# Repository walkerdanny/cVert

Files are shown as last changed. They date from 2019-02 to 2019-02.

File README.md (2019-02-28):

#☢🎹 cVert 🎛☢

### A truly random MIDI controller

YouTube video:

<a href="http://www.youtube.com/watch?feature=player_embedded&v=vMFJ8gjN8Ac
" target="_blank">Video Emo</a>

cVert is a MIDI controller which plays completely random notes based on the radioactive decay of radioisotopes.

Find out more about cVert [on my website](http://danny.makesthings.work/cVert) or [in this zine](https://github.com/walkerdanny/cVert/blob/master/documentation/zine.pdf).

All documentation, code, mechanical files, gerbers etc. are included in this repository. A list of libraries required to compile the software is included in the "electrical" directory.

### Disclaimer: Don't play with radioisotopes unless you're completely sure what you're doing. I'm not responsible if you decide to mess with a dangerous material without taking the proper precautions. Background radiation in most areas will give you a sufficient amount of counts to make cVert a useful tool without introducing extra radioactive material.

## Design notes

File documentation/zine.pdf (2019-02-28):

# cVert

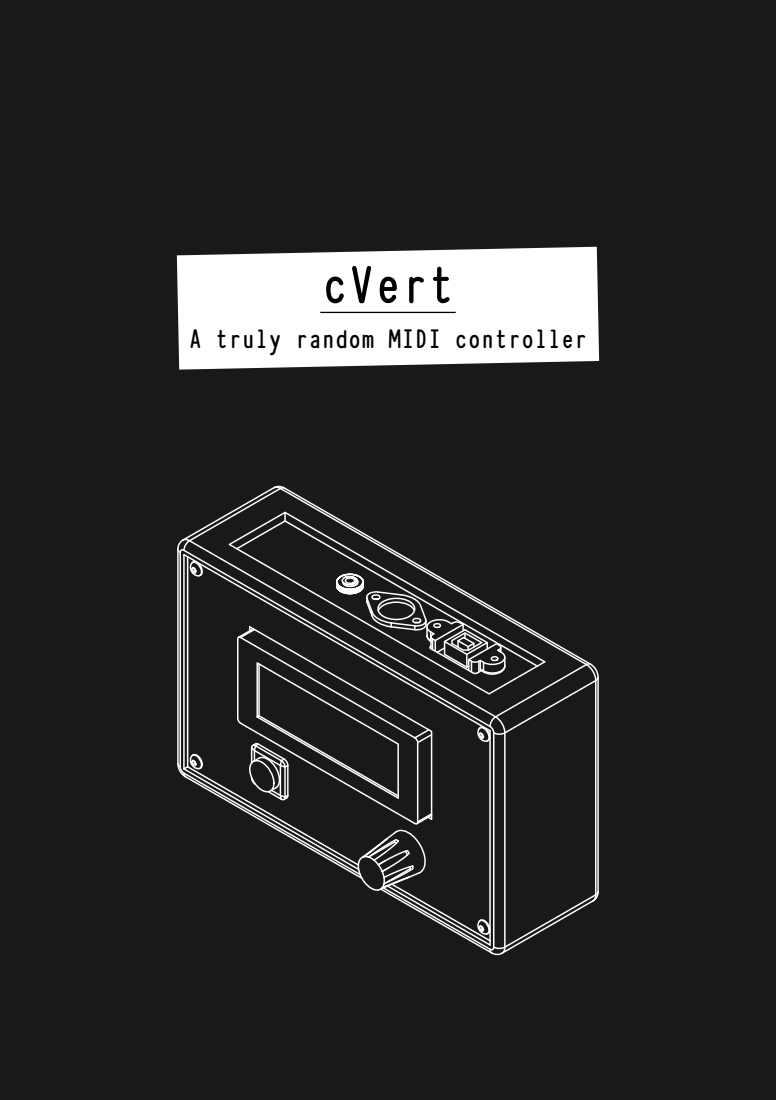
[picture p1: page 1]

A truly random MIDI controller

# What?

cVert qsee-vurtT is a different type of MIDI controller.

Rather than imitating a traditional instrument, cVert generates random notes at random times, based on the radioactive decay of unstable elements.

cVert contains a Geiger–Müller tube, which detects radioactivity. It uses this as an input to generate MIDI notes. Since the decay of unstable isotopes is inherently unpredictable, the notes which are generated are truly and completely random.

cVert can limit the notes it generates to suit a specifc scale or range, according to a series of user selected parameters.

cVert also features a 32 step sequencer. The steps of the sequencer are filled with randomly selected notes, one of which will change each time a
a radioactive decay is detected.

# What for?

cVert can be used for a huge range of weird thingsY Here are some examples for inspirationY

Music:

Interesting results can be produced by using cVert in sequencer mode to control a drum machineS or to play segments of a chopped up sampleS like an amen break or a vocal clipY

In single note modeS cVert can generate ambient soundsY Using it to play a reverbed piano provides relaxingS contemplative background musicY

cVert can also be used to add an unpredictable element to a live performanceY Utilising the MIDI out feature enables cVert to be easily integrated into an existing live setupY Please consider the experimental nature of cVert when doing thisS as the MIDI out is not isolated and may be unreliableY

WARNING: DO NOT MESS WITH RADIOISOTOPES UNLESS YOU KNOW WHAT YOUNRE DOINGY Stick to just background radiation if youNre not completely sureY

Generative art:

When combined with the right software0 cVert can be used to produce random visual art2

Using the IMidiBusI library and Processing0 cVert can provide a random input for a generative artwork2 In fact0 all of the background art in this zine was generated using this techniquek cVert can also be used with platforms such as openFrameworks or Cinder0 or to control web1based applications via the Web MIDI API2

If the range of possible pitches and note numbers -)1x27D is not big enough for your application0
a recommended technique is to use a counter which constantly increments up to your desired maximum value2 cVert can then be used to stop the counter when a note is played0 resulting in a random number in a useful range2

Weird stuff:

If you really want to dive into the nitty gritty of what cVert can be used for0 Pure Data is a graphical programming environment which lets you process MIDI data on the fly2 It can do lots of fun things0 including live audio and visuals2

# How is it made?

cVert is an open-source projectS so all of the design files are available free of charge so that you can make your own.

The functional part of cVert is an Arduino Pro MicroS a cheap Geiger counter module and a few external pars such as a 555 timer and some resistors. While the components are fairly simpleS having a basic knowledge of electronics Cor help from someone who doesB is recommended if you want to build your own.

A custom PCB is available for cVert to make assembly simpleS however it can also be built
on perf board. This way cVert can suit the needs of individuals who want to add features or change componentsS whilst being permanent enough for a regularly used device.

The case for cVert is designed to be 3D printed and laser cut. While these technologies are becoming more accessible via hackerspaces etcS they are not yet available to all. The internals of cVert can therefore be fitted into a standard ABS project boxS available from a range of online stores Caluminium not recommended as it may attenuate the radiationB.

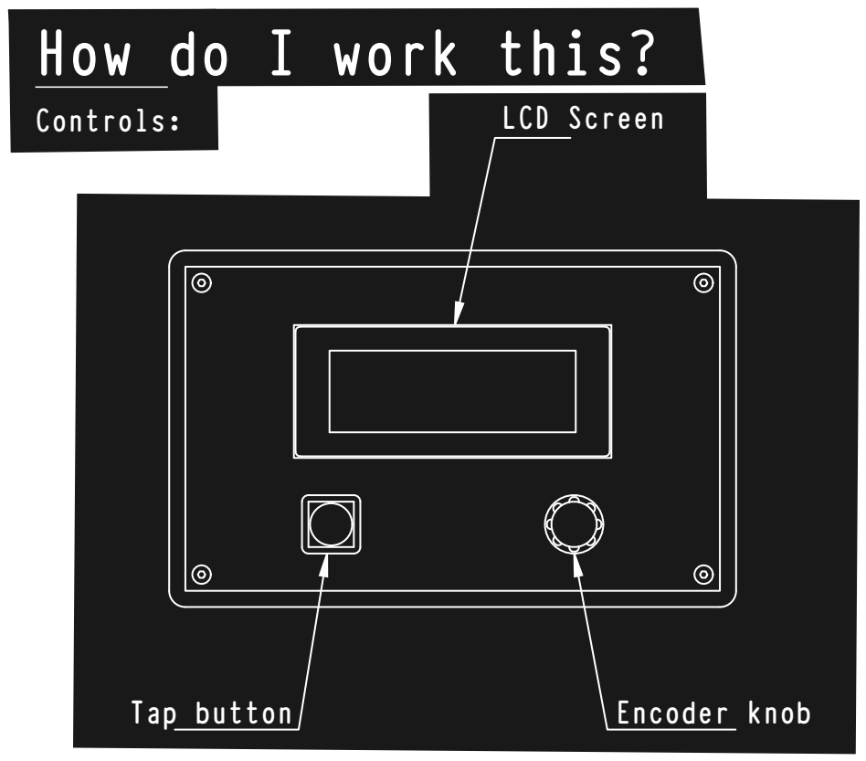
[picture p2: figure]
How do I work this?; LCD Screen; Tap button; Encoder knob; Controls:

The front panel features a 20 x 4 character LCD display, an encoder knob and a tap button.

Turn the encoder knob to navigate the menu or to change a parameter, and click it in to select. Clicking and holding the encoder knob will clear all steps from the step sequencer.

The tap button is used to simulate a decay event, i.e. to force cVert to generate a random note right now.

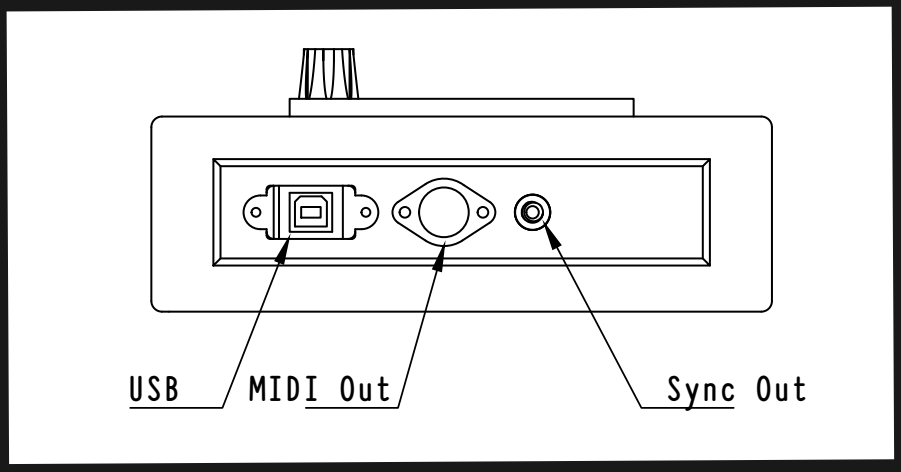
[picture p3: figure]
USB; MIDI Out; Sync Out

The rear panel features connections for USBO MIDI and for syncing external devices.

The USB plug is used to provide power to cVert and to communicate with a computer when used as a USB MIDI controller.

The 5 pin DIN socket is used to provide MIDI out to external hardware synthesisers etc. cVert still needs to be powered via USB 0e.g. a phone chargerR when using hardware synthesisers.

The 3.5mm jack provides a 5V clock signal 00.5ms high pulseO tip positiveR for syncing cVert with external hardware.

Rear Panel:

4 | 1 | 2 | 3

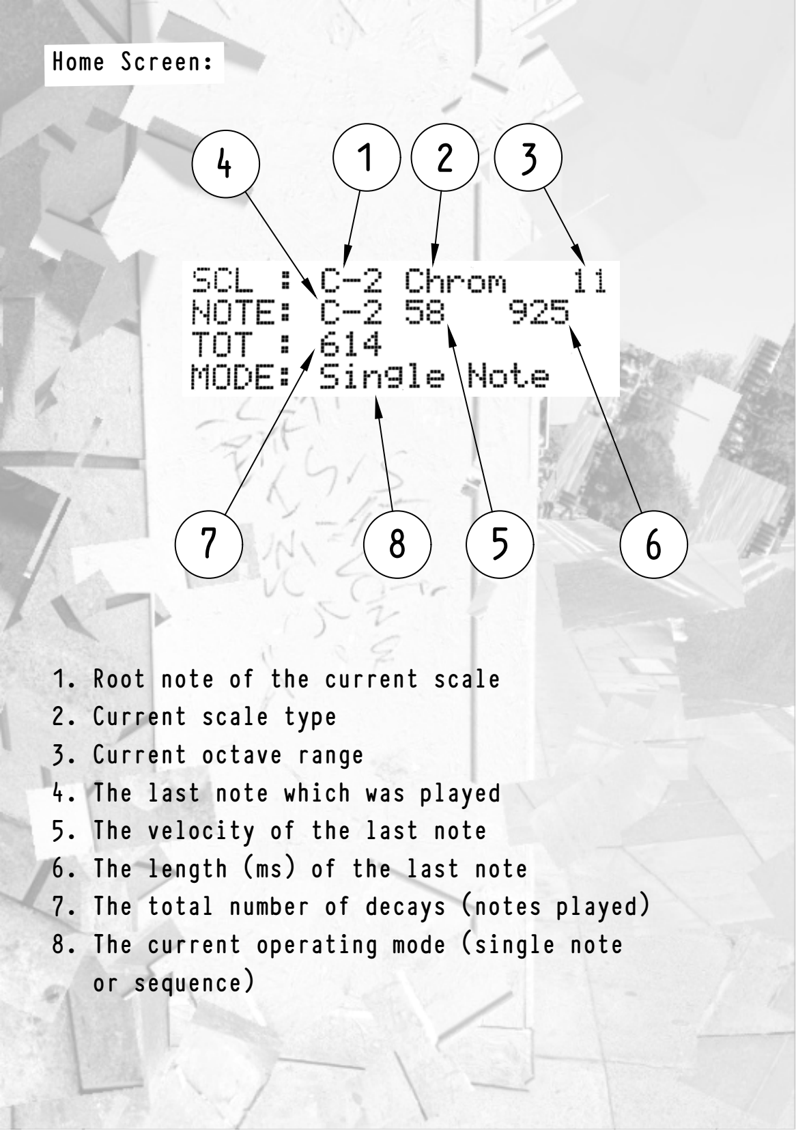
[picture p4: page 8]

### 1. Root note of the current scale 2. Current scale type 3. Current octave range 4. The last note which was played 5. The velocity of the last note 6. The length (ms) of the last note 7. The total number of decays (notes played) 8. The current operating mode (single note

or sequence)

7 | 8 | 5 | 6

Home Screen:

Menu Options:

Click the encoder knob in when at the home screen to enter the menuV

HOME x Returns to the home screenV

Mode x Switches between single note and sequencer modesV

Scale Type x Change the scale which notes are selected fromV "None" means the same note is always playedV Use "Chromatic" to play all notes within the selected rangeV

Root Note x Selects the root note of the scale/ from Cx2 to G8V

Range x The number of octaves of the selected scale to select notes fromV )x11V

Min(Max Velocity: Change the upper and lower limits of the range of velocities to play notes atV Set these to be equal for no velocity variationV

Note length: The length 8in msv to play each note for in single note modeV

Sequencer steps - The number of steps to use when in sequencer mode. 4E 8E 16 or 32.

Sequencer BPM - Sets the tempo in beats per minute of the sequencer. Only approximate due to microcontroller limitationsE use MIDI notes if true synchronisation is needed.

Sequencer divider - number of times per beat a note will be played.

Brightness - Adjusts the brightness of the case LEDsE if present.

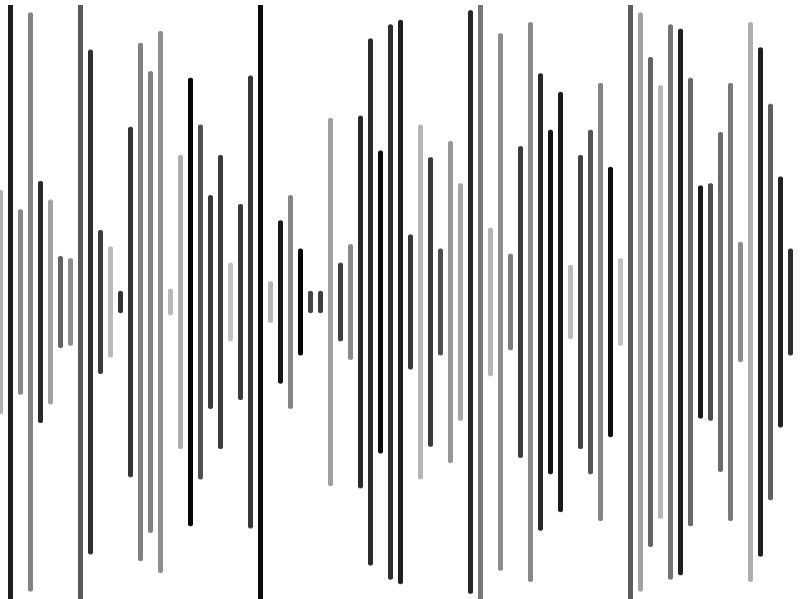
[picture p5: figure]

# More Info

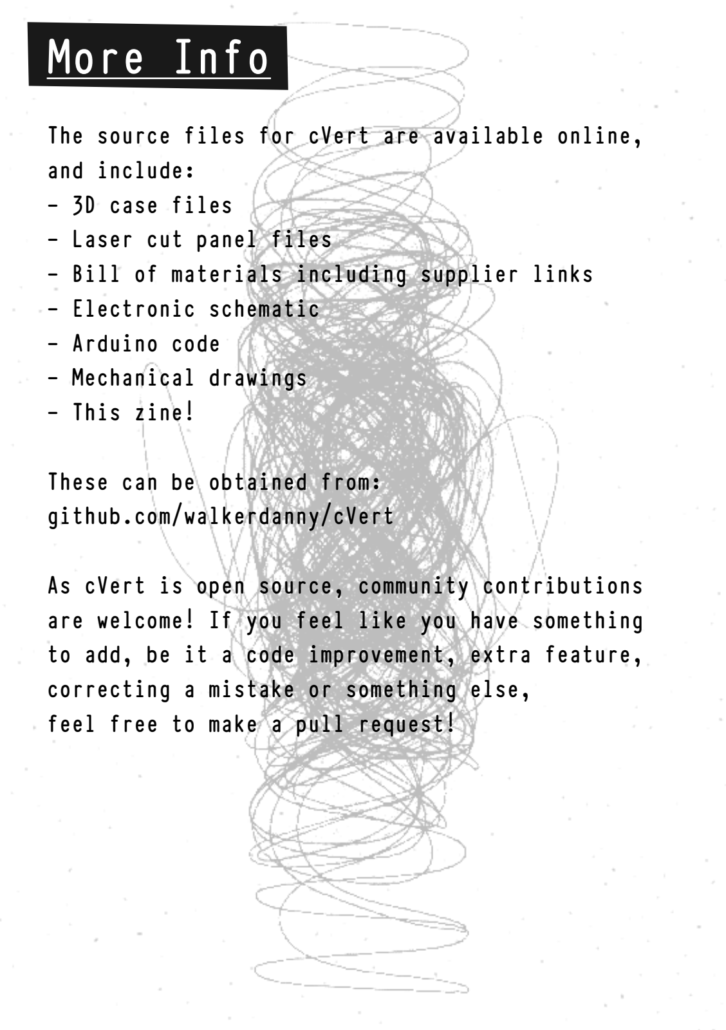
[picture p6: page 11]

The source files for cVert are available online, and include:
- 3D case files
- Laser cut panel files
- Bill of materials including supplier links
- Electronic schematic
- Arduino code
- Mechanical drawings
- This zineA

These can be obtained from: github.com/walkerdanny/cVert

As cVert is open source, community contributions are welcomeA If you feel like you have something to add, be it a code improvement, extra feature, correcting a mistake or something else,
feel free to make a pull requestA

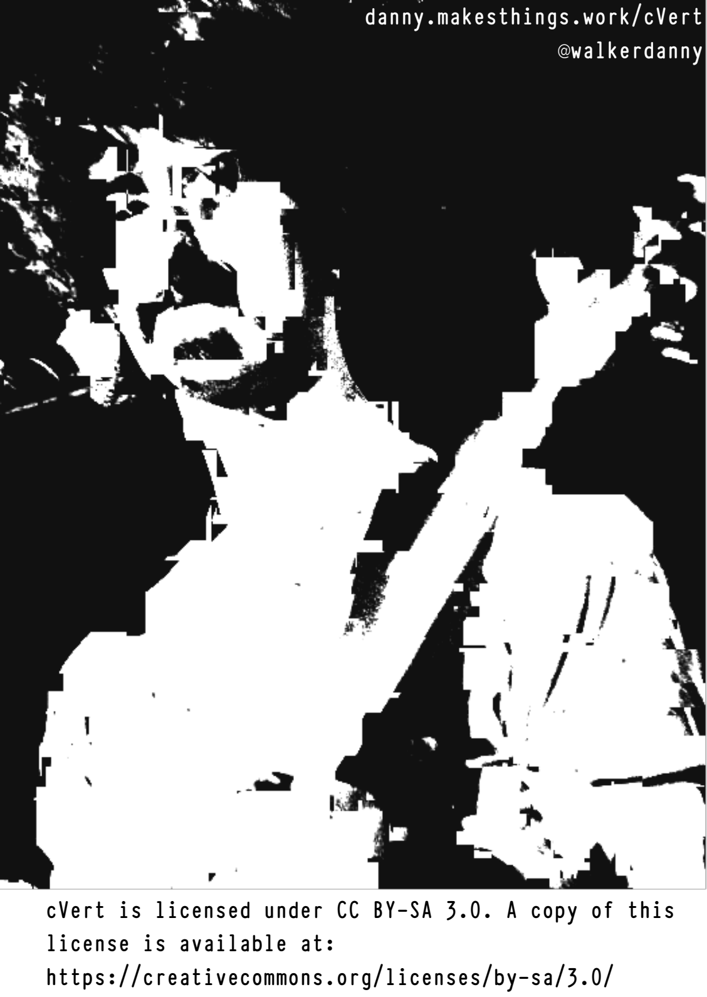
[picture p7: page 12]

cVert is licensed under CC BY-SA 3.0. A copy of this license is available at:
https://creativecommons.org/licenses/by-sa/3.0/danny.makesthings.work/cVert @walkerdanny

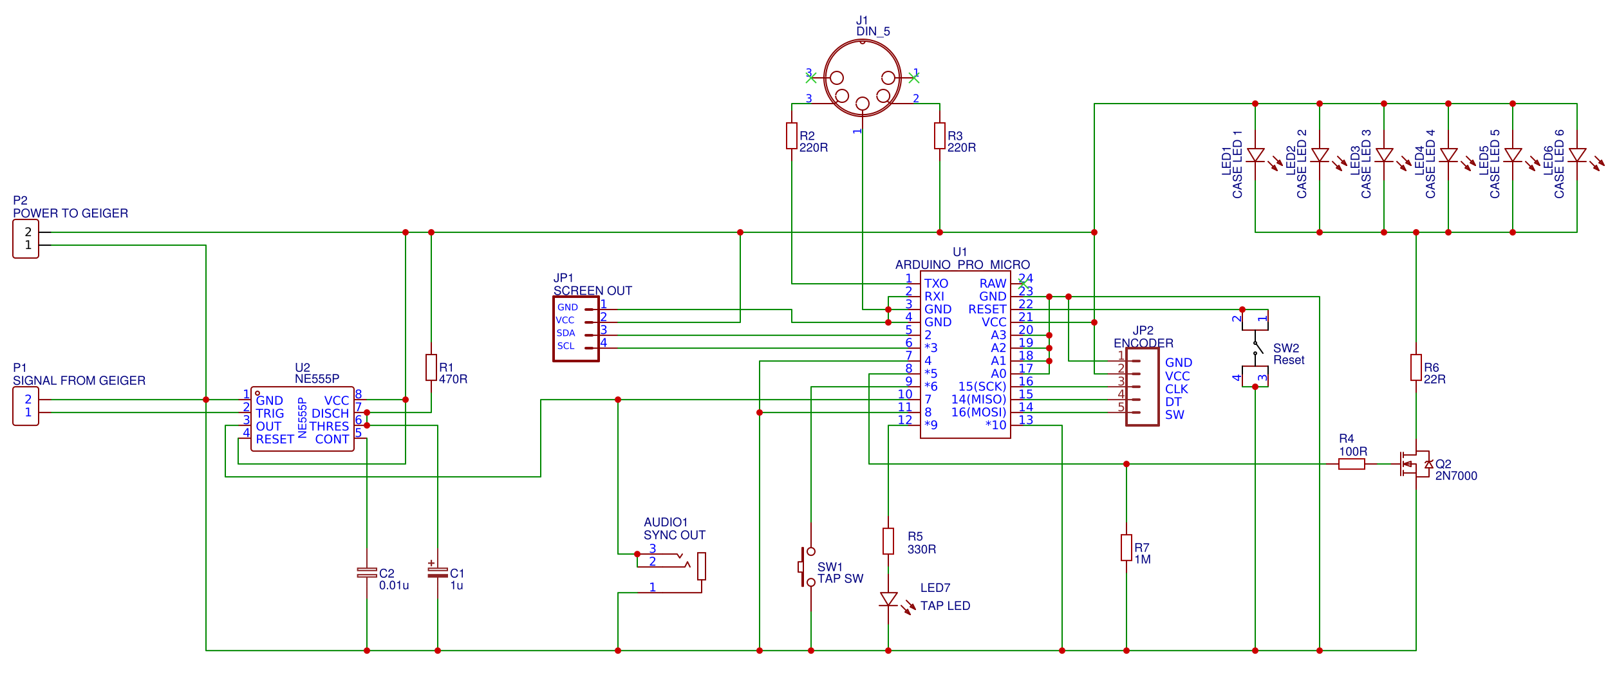
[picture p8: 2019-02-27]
electrical/schematic.png

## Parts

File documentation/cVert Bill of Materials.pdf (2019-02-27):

cVert Bill of Materials | Rev 0 - February 2019
Note: Required components are the absolute minimum to build a working cVert. To build one as featured in the documentation, all optional components should be included. Some consumables have been omitted (solder, superglue, hot glue etc.). Tools are also not listed.
Double check all components before ordering. If in doubt, email and ask.
Name | Required/Optional | Quantity | Source | Link | Notes
Arduino Pro Micro | R | 1 Online | https://www.sparkfun.com/products/12640 5V version needed. Clones available from Chinese drop shipping websites/eBay
Geiger Counter module | R | 1 Online | https://www.banggood.com/Assembled-DIY-Geiger-Counter-Kit-Module-Miller-Tube-GM-Tube-Nuclear-Radiation-Detector-p-1136883.html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 Also avaiable on AliExpress. Ensure it includes the tube before ordering.
20 x 4 LCD Module with I2C | R | 1 Online | https://www.banggood.com/IIC-I2C-2004-204-20-x-4-Character-LCD-Display-Module-Yellow-Green-p-908821.html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 Available elsewhere, ensure it includes I2C
Rotary Encoder module | R | 1 Online | https://www.banggood.com/KY-040-Rotary-Decoder-Encoder-Module-For-Arduino-AVR-PIC-p-914010.html?rmmds=search Available elsewhere, ensure it includes a switch and a D-Shaft for the knob to fit
Illuminated momentary push switch | R | 1 Maplin | https://uk.rs-online.com/web/p/push-button-switches/6911634/ Maplin is now defunct, linked button is similar but may require a different size hole in the panel
5 Pin, 180 Degree DIN Socket | R | 1 Maplin | https://www.ebay.co.uk/p/5-Pin-DIN-Chassis-Panel-Mount-Female-Socket-Connector-Solder-Midi-Cable-Adapter/1590247802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 Maplin is now defunct, linked socket is similar. Screws/nuts may need to be purchased separately.
3.5mm female socket, panel mount | R | 1 Maplin | https://www.ebay.co.uk/itm/3-5mm-Stereo-Jack-Socket-Chassis-Panel-Mount-Solder-Connector-Audio-Adapter/310760800278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 Maplin is now defunt, linked socket is similar.
NE555 Timer, 8 pin DIP | R | 1 Own stock https://www.ebay.co.uk/itm/NE555-NE555P-555-Timer-IC-8-pin-DIL-Pack-of-10/142389711946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 Common IC, available from any electronics store
Resistors (various) | R | | 4 Own stock | | 1/4 watt resistors of various values, see schematic. Can be ordered individually or in bulk. 2 additional if using case LEDs
Electrolytic capacitor, 1uF 16V | R | | 1 Own stock | | Available from lots of online retailers.
Ceramic capacitor, 10pF | R | | 1 Own stock | | Available from lots of online retailers.
2.54mm pitch female header | R | 47 Online | https://www.ebay.co.uk/itm/PCB-Header-Pins-Sockets-2-54mm-Pitch-Straight-Plugs-PIC-Arduino-Pi-Breadboard/131921173215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 Needed in smaller sections, quantity is the number of pins total.
Dupont male-female cables | R | 19 Online | https://www.ebay.co.uk/itm/40-pcs-Dupont-Cables-M-F-M-M-F-F-Jumper-Breadboard-Wire-GPIO-Ribbon-Pi-Arduino/263021195544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 Helps to order a selection of genders and colours. Some will be cut up and soldered onto things.
Perfboard (70x40mm) | R | 1 Online | https://www.banggood.com/40pcs-FR-4-Double-Side-Prototype-PCB-Printed-Circuit-Board-p-995732.html?rmmds=search Not required if using the custom PCB.
USB A to micro USB cable | R | | 1 Own stock | | For programming the Arduino. Can also be used as the main power/ data cable if desired.
P2N2222A Transistor | O | | 1 Own stock | | Available from lots of online retailers.
Custom cVert PCB | O | | 1 JLCPCB | See GitHub | Currently unavailable for purchase, but Gerbers are available for you to order your own. I may have some spares if you email me.
3D Printed Case (+ knob) | O | | 1 Self print | See GitHub | Can be printed via an online printing service, preferably black PLA
Laser cut acrylic panels (set) | O | 1 Self made See GitHub | Can be laser cut via onlie service if needed. Use 3mm translucent green acrylic. Possible to manufacture by hand.
M3 brass heat set inserts | O | 4 Online | https://www.ebay.co.uk/itm/M3-M4-M5-M6-Threaded-Solid-Brass-Press-in-Barbed-Inserts-for-plastic-press-fit/262993790868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
Black M3x12 dome head machine screw | O | 4 Online | https://www.ebay.co.uk/itm/M3-BLACK-HIGH-TENSILE-10-9-BUTTON-HEAD-ALLEN-BOLTS-SELF-COLOUR-DOME-SOCKET-SCREW/121829578789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
Black enamel spray paint | O | 1 Homebase https://www.homebase.co.uk/rust-oleum-painters-touch-craft-enamel-spray-paint-black-matt-150ml_p232471
Grey automotive spray primer | O | | 1 Own stock
1206 bright white LEDs on flying leads | O | 6 Online | https://www.ebay.co.uk/itm/T0402-T0603WM-1206-Pre-soldered-micro-litz-wired-leads-SMD-Led-Mutil-color-Lots/282536517380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 Bought pre-soldered to save hassle, would recommend. For illuminating the case panel
USB B male to USB A male cable | O | | 1 Online
USB B panel mount to micro USB cable | O | 1 Online | https://www.ebay.co.uk/itm/90-Degree-Left-Angled-Micro-USB-5pin-Male-to-USB-B-Female-Panel-Mount-Type-Cable/232826010458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 Available from Chinese drop shipping sites

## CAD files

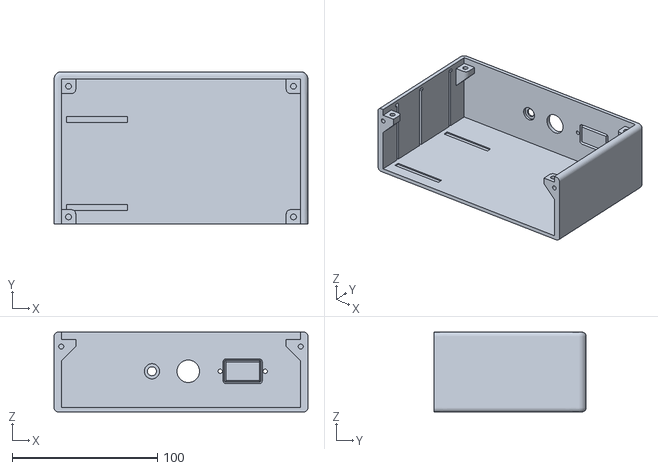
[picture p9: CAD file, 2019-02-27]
mechanical/STL/Case-Main.stl
175.0 x 105.0 x 55.0

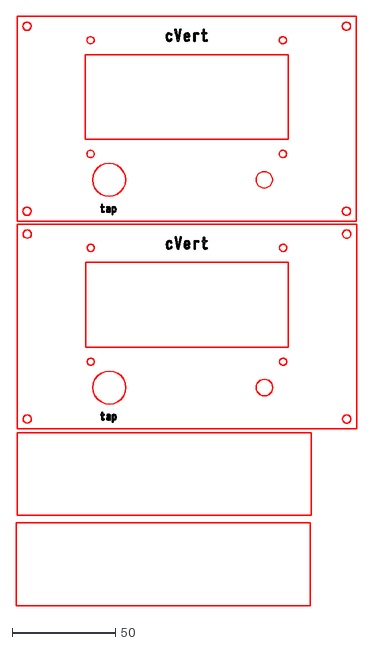
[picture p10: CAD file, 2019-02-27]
mechanical/frontpanel.dxf
164.4 x 284.8

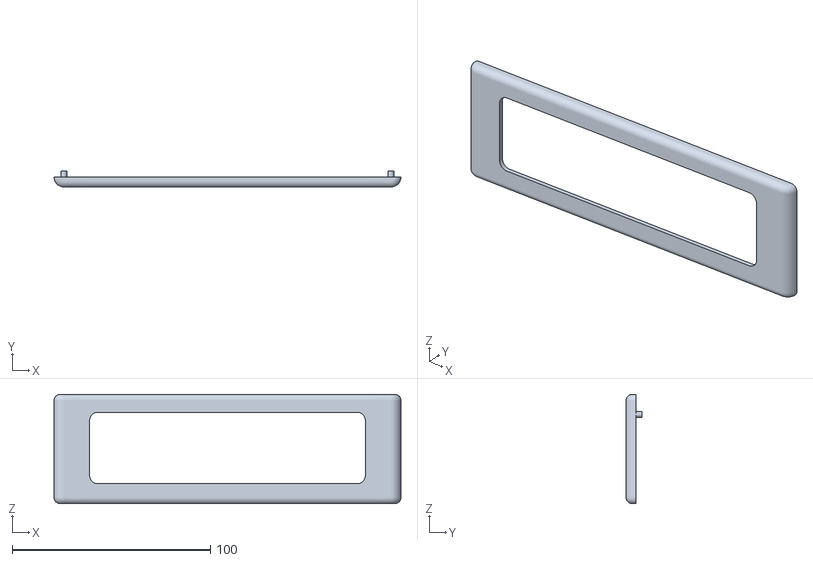
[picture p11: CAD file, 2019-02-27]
mechanical/STL/Case-Front.stl
175.0 x 8.00 x 55.0

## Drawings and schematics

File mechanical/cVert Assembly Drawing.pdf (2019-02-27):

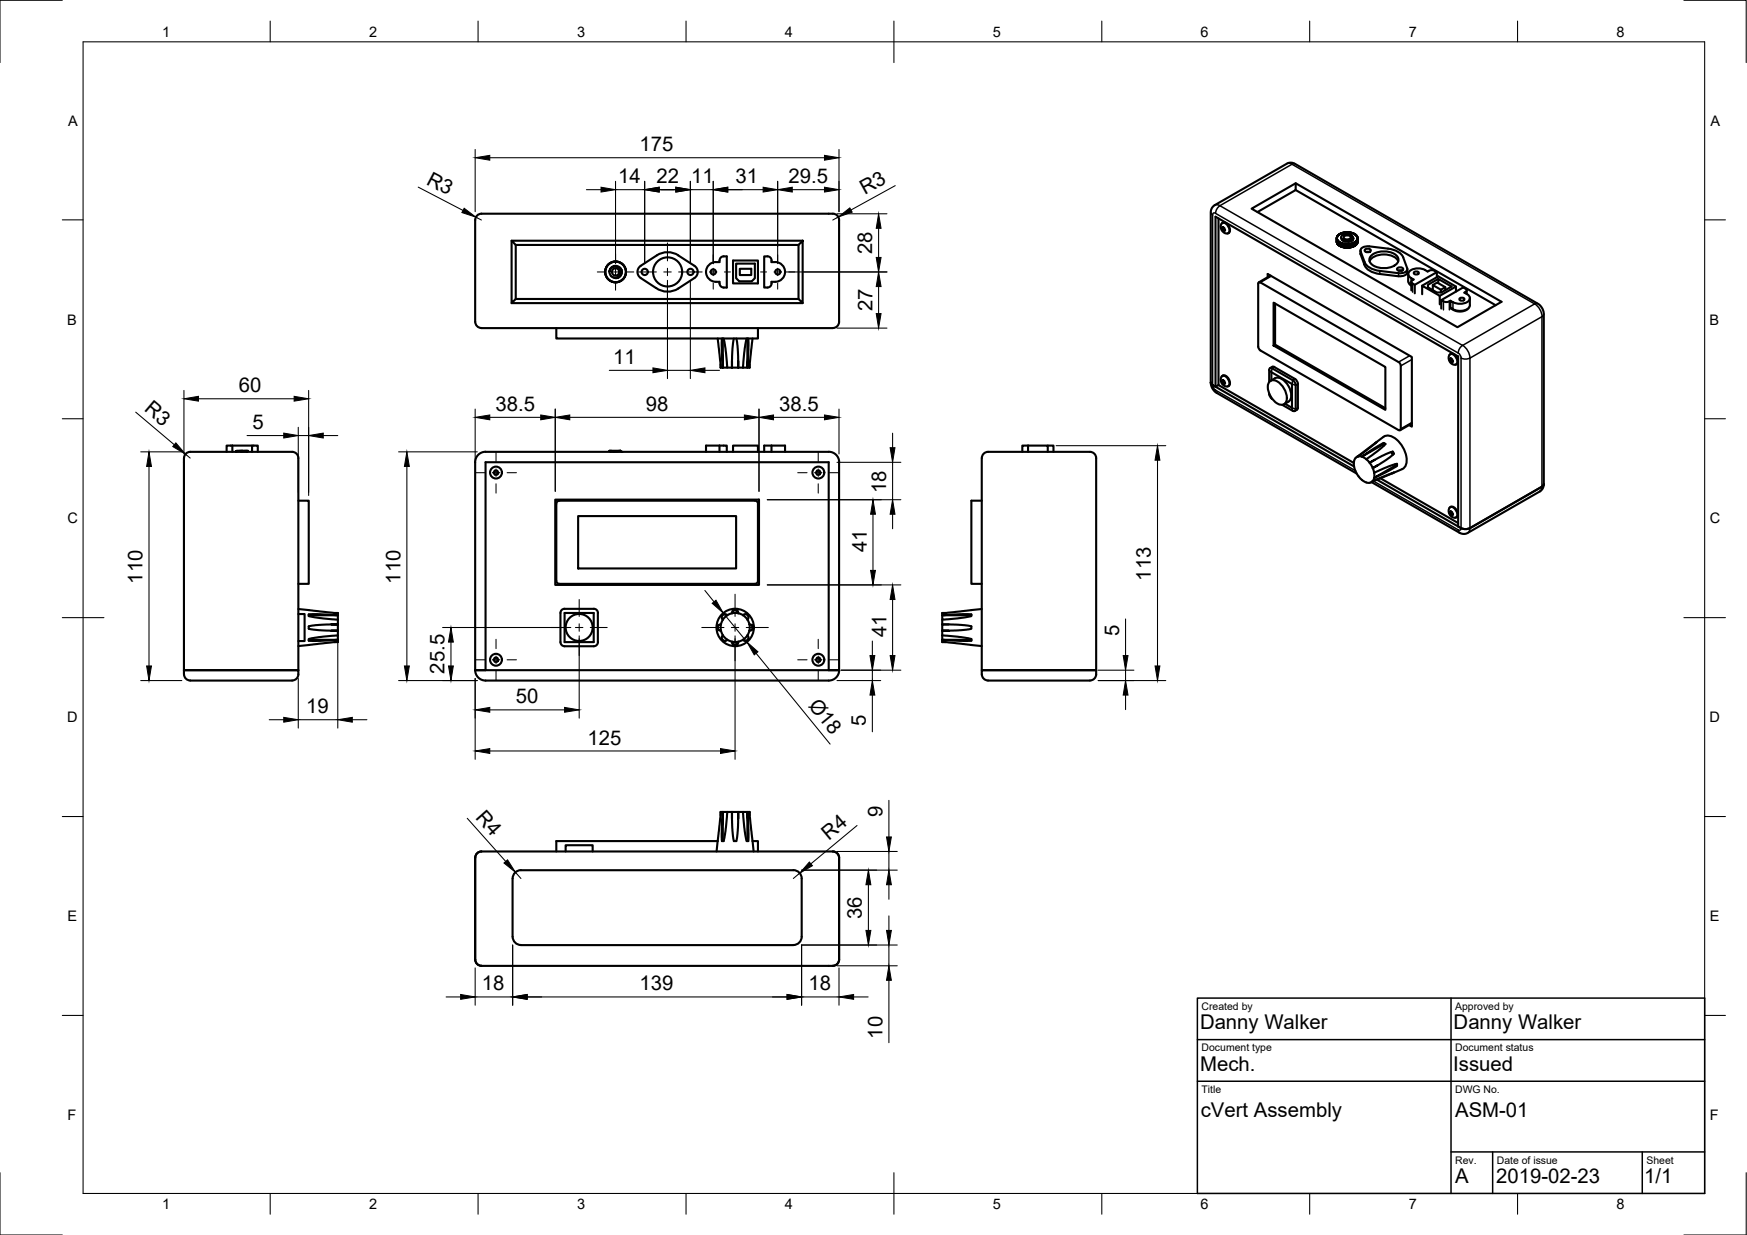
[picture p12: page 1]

Created by Danny Walker | Approved by Danny Walker

Document type Mech. | Document status Issued

Title cVert Assembly | DWG No. ASM-01

Rev. | Date of issue | Sheet

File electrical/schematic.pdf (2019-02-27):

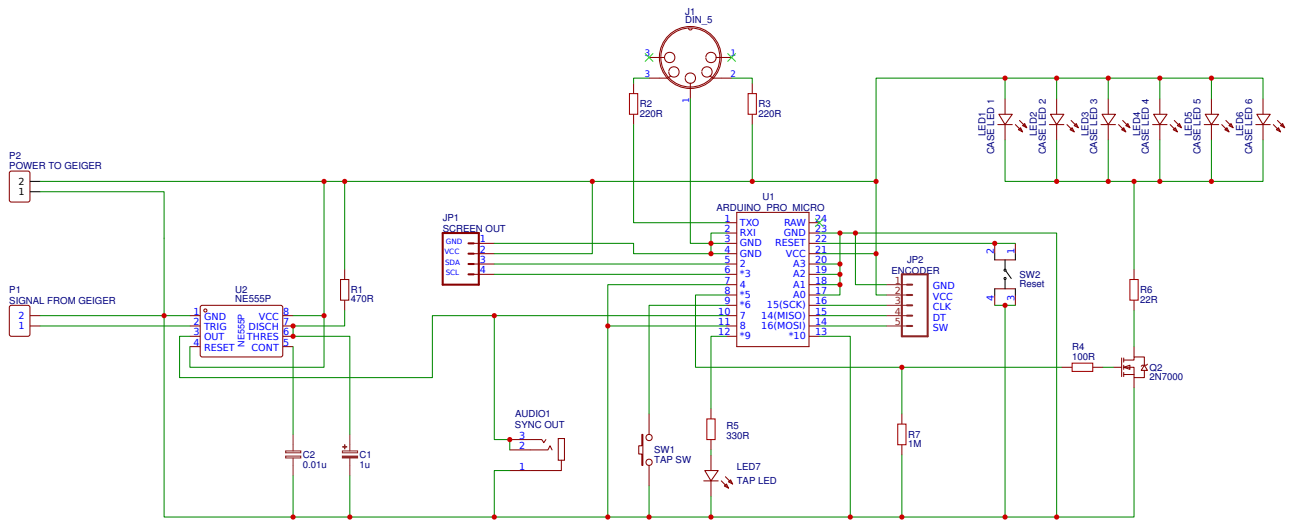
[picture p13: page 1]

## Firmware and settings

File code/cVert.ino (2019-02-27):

/* cVert software by Danny Walker, 2019
 *  
 *  Designed to run on Arduino Pro Micro
 *  
 *  See github.com/walkerdanny/cVert for more info
 *  
 *  CC BY-SA 3.0
 */


/*TODO:
  - User save of settings in 4 (?) preset slots
  - Find a way of testing Serial MIDI properly
  - Find ways of reducing screen flicker - update less frequently?
  - Try and correct for tempo fluctuations of sequencer. Maybe do maths for next note immediately after the previous note is played, and then just send it to MIDI using the interrupt.
  - Remove a lot of the debug serial messages
  - Implement control change messages? Separate mode? Is there enough memory?
  - Add in more scales
  - Find a less bodgey way of restricting the notes to 0-127 while still maintaining the randomness

*/
#include <FlexiTimer2.h>
#include <Wire.h>
#include <hd44780.h>
#include <hd44780ioClass/hd44780_I2Cexp.h>
#include <TimerOne.h>
#include <EEPROM.h>

#define LCD_COLS 20
#define LCD_ROWS 4

hd44780_I2Cexp display; // declare object: auto locate & config exapander chip


// MIDI Globals
uint8_t modeNumber = 0;
String baseNotes [] = {"C", "C#", "D", "D#", "E", "F", "F#", "G", "G#", "A", "A#", "B"};
uint8_t rootNoteNumber = 57;
String rootNoteStr = "A4";
String scaleTypesString [] = {"None", "Major", "Minor", "Blues", "Chrom", "Dorian", "Har-Min", "Mel-Min"};
uint8_t scales [8][12] = {
  {0, 0, 0, 0, 0, 0, 0,  0,   0,   0,   0,   0},
  {0, 2, 4, 5, 7, 9, 11, 100, 100, 100, 100, 100},
  {0, 2, 3, 5, 7, 8, 10, 100, 100, 100, 100, 100},
  {0, 2, 3, 4, 5, 7, 9,  10,  11,  100, 100, 100},
  {0, 1, 2, 3, 4, 5, 6,  7,   8,   9,   10,  11},
  {0, 2, 3, 5, 7, 9, 10, 100, 100, 100, 100, 100},
  {0, 2, 3, 5, 7, 8, 11, 100, 100, 100, 100, 100},
  {0, 2, 3, 5, 7, 8, 9,  10,  11,  100, 100, 100}
};
byte seqNotes [32] = {255, 255, 255, 255, 255, 255, 255, 255, 255, 255, 255, 255, 255, 255, 255, 255, 255, 255, 255, 255, 255, 255, 255, 255, 255, 255, 255, 255, 255, 255, 255, 255};
byte seqVels [32] = {255, 255, 255, 255, 255, 255, 255, 255, 255, 255, 255, 255, 255, 255, 255, 255, 255, 255, 255, 255, 255, 255, 255, 255, 255, 255, 255, 255, 255, 255, 255, 255};
byte seqDivs [6] = {1, 2, 4, 8, 16, 32};

uint8_t scaleLengths [] = {1, 7, 7, 9, 12, 7, 7, 9};
uint8_t scaleTypeIndex = 1;
uint8_t octRange = 1;
uint8_t minVel = 0;
uint8_t maxVel = 127;
int noteLength  = 1000;
uint8_t seqLengths [] = {4, 8, 16, 32};
uint8_t seqLengthIndex;
uint8_t seqTempo = 120;
uint8_t seqIndex = 0;
uint8_t seqFillIndex = 0;
uint8_t seqDivIndex = 2;
byte fadeAmount = 0;

// Menu globals
byte menuStatus = 0;
int8_t seqLengthOffset = 0;
int8_t seqTempoOffset = 0;
int8_t seqDivOffset = 0;
int8_t modeOffset = 0;
int8_t selectedLine = 0;
int8_t menuRootOffset = 0;
int8_t scaleMenuOffset = 0;
int8_t rootNoteOffset = 0;
int8_t rangeOffset = 0;
int8_t minVelOffset = 0;
int8_t maxVelOffset = 0;
int8_t fadeOffset = 0;
int noteLengthOffset = 0;
boolean displayingAbout = false;

// Home screen globals
String currentNoteString = "";
unsigned int totalCounts = 0;
unsigned int countRate = 0;

int buttonTimeout = 200;
long buttonMillis = -buttonTimeout;
boolean play = false;
boolean displayButtonPress = false;

//byte offAmount = 0;
//byte counter = 0;
//boolean pin5State = false;

void checkForSeqReset() {
  if (digitalRead(6) == LOW && (isButtonPressed() == 3 || isButtonPressed() == 1)) {
    for (uint8_t j = 0; j < sizeof(seqNotes); j++) {
      seqNotes[j] = 255;
      seqVels[j] = 255;
    }
  }
}

String noteNumberToString(int number) {
  return baseNotes[number % 12] + String((number / 12) - 2);
}

int stringToNoteNumber(String noteName) {
  uint8_t ind;
  for (unsigned int i = 0; i < sizeof(baseNotes); i++) {
    if (noteName.substring(0, noteName.length() - 1).equals(baseNotes[i])) {
      ind = i;
    }
  }
  return (noteName.substring(noteName.length() - 1, noteName.length()).toInt() + 2) * 12 + ind;
}

void readLastConfiguration() {
  // Big, big bodge
  rootNoteNumber = EEPROM.read(1);
  rootNoteNumber = constrain(rootNoteNumber, 0, 127);
  octRange       = EEPROM.read(2);
  octRange = constrain(octRange, 0, 11);
  minVel         = EEPROM.read(3);
  minVel = constrain(minVel, 0, 127);
  maxVel         = EEPROM.read(4);
  maxVel = constrain(maxVel, 0, 127);
  seqLengthIndex = EEPROM.read(5);
  seqLengthIndex = constrain(seqLengthIndex, 0, 10);
  seqTempo       = EEPROM.read(6);
  seqTempo = constrain(seqTempo, 0, 200);
  seqDivIndex    = EEPROM.read(7);
  seqDivIndex = constrain(seqDivIndex, 0, 4);
  modeNumber     = EEPROM.read(8);
  modeNumber = constrain(modeNumber, 0, 1);
  byte i1        = EEPROM.read(9);
  byte i2        = EEPROM.read(10);
  scaleTypeIndex = EEPROM.read(11);
  fadeAmount     = EEPROM.read(12);
  fadeAmount = constrain(fadeAmount, 0, 100);
  scaleTypeIndex = constrain(scaleTypeIndex, 0, 7);
  noteLength = word(i2, i1);
  noteLength = constrain(noteLength, 0, 2000);
}


void setup() {
  Serial.begin(9600);
  Serial.println(F("Booted and doing stuff"));
  Serial1.begin(31250);
  readLastConfiguration();
  if (seqTempo != 0) {
    int msInterval = 60000 / (seqTempo * seqDivs[seqDivIndex]);
    FlexiTimer2::set(msInterval, playSequencer);
    FlexiTimer2::start();
  }
  display.begin(LCD_COLS, LCD_ROWS);
  setupEncoder();
  attachInterrupt(digitalPinToInterrupt(7), countDetected, RISING);
  pinMode(6, INPUT_PULLUP);
  pinMode(5, OUTPUT);
  pinMode(9, OUTPUT);
  if (seqTempo == 0) seqTempo = 120;
  Serial.println(F("Setup Done"));
}

void loop() {

  analogWrite(5, 2*(fadeAmount+fadeOffset));

  if (menuStatus == 0) {
  displayHomescreen();
  } else {
    displayMenu();
  }

  if (millis() - buttonMillis > buttonTimeout) { // Debounce, kinda
  displayButtonPress = false;
  if (digitalRead(6) == LOW) {
      play = true;
      displayButtonPress = true;
      buttonMillis = millis();
    }
  }

  updateEncoder();
  updateNotes();
}

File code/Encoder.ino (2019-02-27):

#include <ClickEncoder.h>

ClickEncoder *encoder;
int16_t lastEnc, encVal;

void setupEncoder(){
  encoder = new ClickEncoder(14,15,16,4);
  Timer1.initialize(1000);
  Timer1.attachInterrupt(timerIsr);
  lastEnc = -1;
  encoder->setAccelerationEnabled(false);
}

void timerIsr() {
  encoder->service();
}

void updateEncoder(){

  switch(menuStatus){
    case 0:
      // Display the home screen, handled elsewhere, encoder does nothing apart from monitor for clicks
      if(isButtonPressed() == 3){
        menuStatus = 13;
      }  else if (isButtonPressed() == 5){
        for (uint8_t j = 0; j < sizeof(seqNotes); j++){
          seqNotes[j] = 255;
          seqVels[j] = 255;
        }
      }
      break;

    case 1:
      // Mode submenu
      encVal = 0;
      encVal = encoder->getValue();
      if(lastEnc += encVal != lastEnc){
        lastEnc += encVal;
        modeOffset += encVal;
        if(modeNumber + modeOffset < 0){
          Serial.println(F("Bottom of modes list selected and scrolling down  "));
          modeOffset = -modeNumber;
        }
        if(modeNumber + modeOffset >= 2){
          Serial.println(F("Top of modes list selected and scrolling up  "));
          modeOffset = 1 - modeNumber;
        }
      }

      if(isButtonPressed() == 3){
        modeNumber += modeOffset;
        menuStatus = 13;
        modeOffset = 0;
        EEPROM.update(8, modeNumber);
      }
      break;
      
    case 2:
      // Scale type submenu
      encVal = 0;
      encVal = encoder->getValue();
      if(lastEnc += encVal != lastEnc){
        lastEnc += encVal;
        scaleMenuOffset += encVal;
        if(scaleTypeIndex + scaleMenuOffset < 0){
          Serial.print(F("Top of scales list selected and scrolling up  "));
          Serial.println(sizeof(scaleTypesString));
          scaleMenuOffset = -scaleTypeIndex;
        }
        if(scaleTypeIndex + scaleMenuOffset >= sizeof(scaleLengths)){
          Serial.print(F("Bottom of scales list selected and scrolling down  "));
          scaleMenuOffset = sizeof(scaleLengths) - scaleTypeIndex -1;
          Serial.println(scaleMenuOffset + scaleTypeIndex);
        }
      }

      if(isButtonPressed() == 3){
        scaleTypeIndex += scaleMenuOffset;
        menuStatus = 13;
        scaleMenuOffset = 0;
        EEPROM.update(11, scaleTypeIndex);
      }
      break;
      
    case 3:
      // Root note submenu
      encVal = 0;
      encVal = encoder->getValue();
      if(lastEnc += encVal != lastEnc){
        lastEnc += encVal;
        rootNoteOffset += encVal;
        if(rootNoteNumber + rootNoteOffset < 0){
          Serial.print(F("Bottom of root notes selected and decreasing  "));
          rootNoteOffset = -rootNoteNumber;
          Serial.println(rootNoteOffset + rootNoteNumber);
        }
        if(rootNoteNumber + rootNoteOffset > 127){
          Serial.print(F("Top of scales list selected and increasing  "));
          rootNoteOffset = 127 - rootNoteNumber;
          Serial.println(rootNoteOffset + rootNoteNumber);
        }
      }

      if(isButtonPressed() == 3){
        rootNoteNumber += rootNoteOffset;
        menuStatus = 13;
        rootNoteOffset = 0;
        EEPROM.update(1, rootNoteNumber);
      }
      break;
      
    case 4:
      // Range submenu
      encVal = 0;
      encVal = encoder->getValue();
      //maxR = (127-rootNoteNumber)/12 + 1; // Stops the MIDI notes from overflowing the 0-127 range
      if(lastEnc += encVal != lastEnc){
        lastEnc += encVal;
        rangeOffset += encVal;
        if(octRange + rangeOffset < 1){
          Serial.print(F("Bottom of offset selected and decreasing  "));
          rangeOffset = -octRange + 1;
          Serial.println(octRange + rangeOffset);
        }
        if(octRange + rangeOffset > (127-rootNoteNumber)/12 + 1){
          Serial.print(F("Top of range selected and increasing  "));
          rangeOffset = (127-rootNoteNumber)/12 + 1 - octRange;
          Serial.println(octRange + rangeOffset);
        }
      }

      if(isButtonPressed() == 3){
        octRange += rangeOffset;
        menuStatus = 13;
        rootNoteOffset = 0;
        EEPROM.update(2, octRange);
      }
      
      break;
      
    case 5:
      // Min. velocity submenu
      encVal = 0;
      encVal = encoder->getValue();
      if(lastEnc += encVal != lastEnc){
        lastEnc += encVal;
        minVelOffset += encVal;
        if(minVel + minVelOffset < 0){
          Serial.print(F("Bottom of min vel selected and decreasing  "));
          minVelOffset = -minVel;
          Serial.println(minVel + minVelOffset);
        }
        if(minVel + minVelOffset > maxVel){
          Serial.print(F("Top of min vel selected and increasing  "));
          minVelOffset = maxVel - minVel;
          Serial.println(minVel + minVelOffset);
        }
      }

      if(isButtonPressed() == 3){
        minVel += minVelOffset;
        menuStatus = 13;
        minVelOffset = 0;
        EEPROM.update(3, minVel);
      }
      break;
      
    case 6:
      // Max. velocity submenu
      encVal = 0;
      encVal = encoder->getValue();
      if(lastEnc += encVal != lastEnc){
        lastEnc += encVal;
        maxVelOffset += encVal;
        if(maxVel + maxVelOffset < minVel){
          Serial.print(F("Bottom of max vel selected and decreasing  "));
          maxVelOffset = minVel -maxVel;
          Serial.println(maxVel + maxVelOffset);
        }
        if(maxVel + maxVelOffset > 127){
          Serial.print(F("Top of max vel selected and increasing  "));
          maxVelOffset = 127 - maxVel;
          Serial.println(maxVel + maxVelOffset);
        }
      }

      if(isButtonPressed() == 3){
        maxVel += maxVelOffset;
        menuStatus = 13;
        maxVelOffset = 0;
        EEPROM.update(4, maxVel);
      }
      break;
      
    case 7:
      // Note length submenu
      encoder->setAccelerationEnabled(true);
      encVal = 0;
      encVal = encoder->getValue();
      if(lastEnc += encVal != lastEnc){
        lastEnc += encVal;
        noteLengthOffset += encVal;
        if(noteLength + noteLengthOffset < 1){
          Serial.print(F("Bottom of note length selected and decreasing  "));
          noteLengthOffset = -noteLength;
          Serial.println(noteLength + noteLengthOffset);
        }
        if(noteLength + noteLengthOffset > 15000){
          Serial.print(F("Top of note length selected and increasing  "));
          noteLengthOffset = 15000 - noteLength;
          Serial.println(noteLength + noteLengthOffset);
        }
      }

      if(isButtonPressed() == 3){
        noteLength += noteLengthOffset;
        menuStatus = 13;
        noteLengthOffset = 0;
        encoder->setAccelerationEnabled(false);
        EEPROM.update(9,lowByte(noteLength));
        EEPROM.update(10,highByte(noteLength));
      }
      break;
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

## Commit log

2019-02-27 First commit
    🤞
    [Case-Front.stl, Case-Main.stl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]
2019-02-27 fixed link 😒
2019-02-27 fixed zine link 🛠
2019-02-28 updated readme 📄
2019-02-28 zine updates and spell check 📖
